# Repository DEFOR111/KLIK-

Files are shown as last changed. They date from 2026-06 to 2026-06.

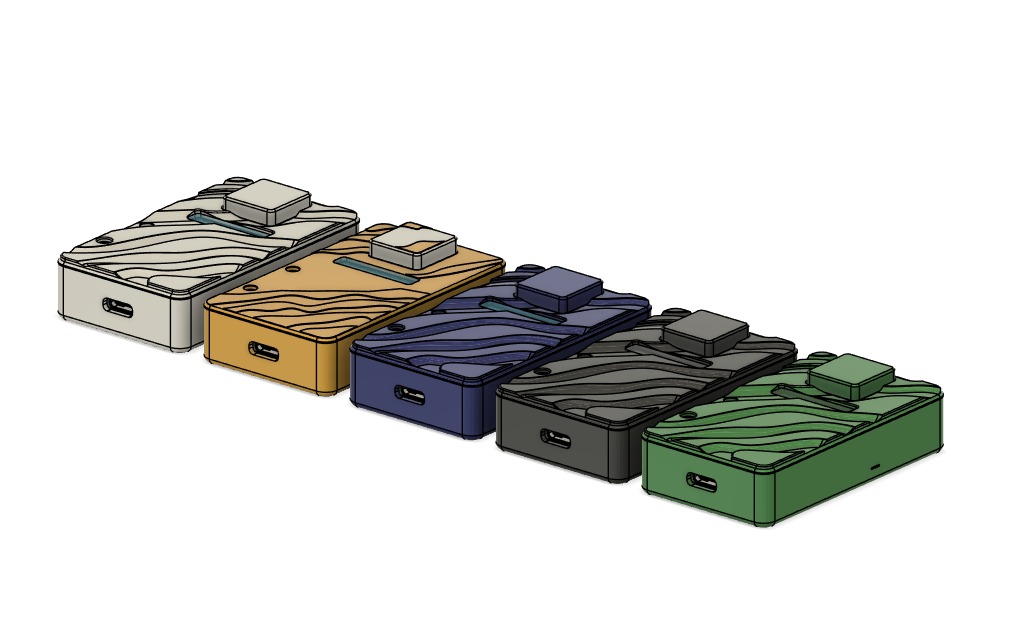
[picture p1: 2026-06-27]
Renders/5 KLIK side view.jpeg

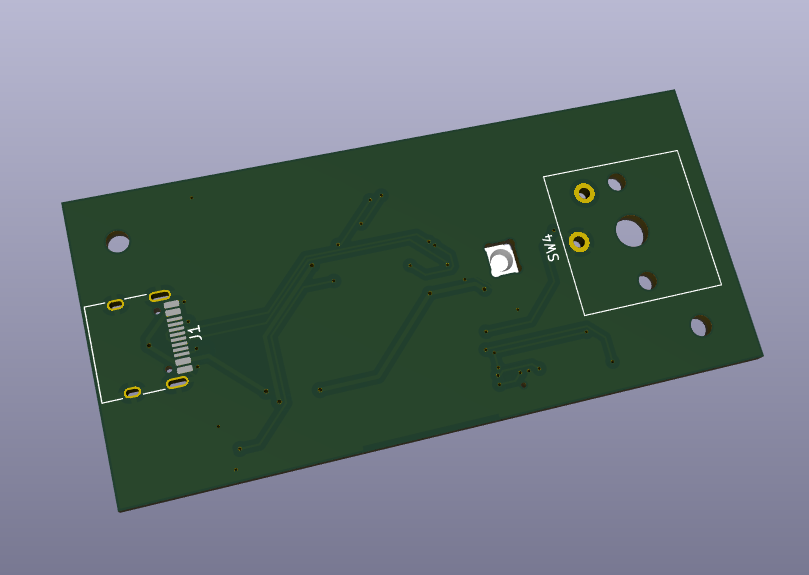
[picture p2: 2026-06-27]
Renders/Top PCB view.png

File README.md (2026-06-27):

# KLIK 
klik is small pocked size device for capturing the ideas or just notes with beatiful design and 5 colors 
WhatsApp Image 2026-06-02 at 11 36 02 AM
front view
WhatsApp Image 2026-06-02 at 11 36 16 AM
up view
WhatsApp Image 2026-06-02 at 11 38 32 AM
best view\
# What does it do? 
* 1. click : the device uses low profile switch which makes it compact and great at the same time
* 2. microphone : captures any idea you say cool thing
* 3. no screen i used screen in first version but its actully useless so now it workd with rgb which gives all feedback you need
* 4. vibration : it is virbrated and make using and cliking it really amazing
# the device parts 
* the device is not just a micphone you can always capture your ideas notions and any staff you want and customize it by easily removing the keycap and using any colour you want making it not only the capture device it is beatiluf custom second brain
* # bom
* you can buy whole parts just for +-90 dollars which makes building not that expensive check all components in BOM.csv
  # PCB
  Снимок экрана 2026-06-10 163932
Снимок экрана 2026-06-10 163853

# building 
to build this device you have to get all materials and then
1. solder full pcb
2. take bottom case screw the pcb place the vbiro motor
3.  then screw the battery holder
4.  after placing battery and all components screw the top case glue the rgb window smoke it with film
5.  put the keycap on switch
6.  turn it on and enjoy

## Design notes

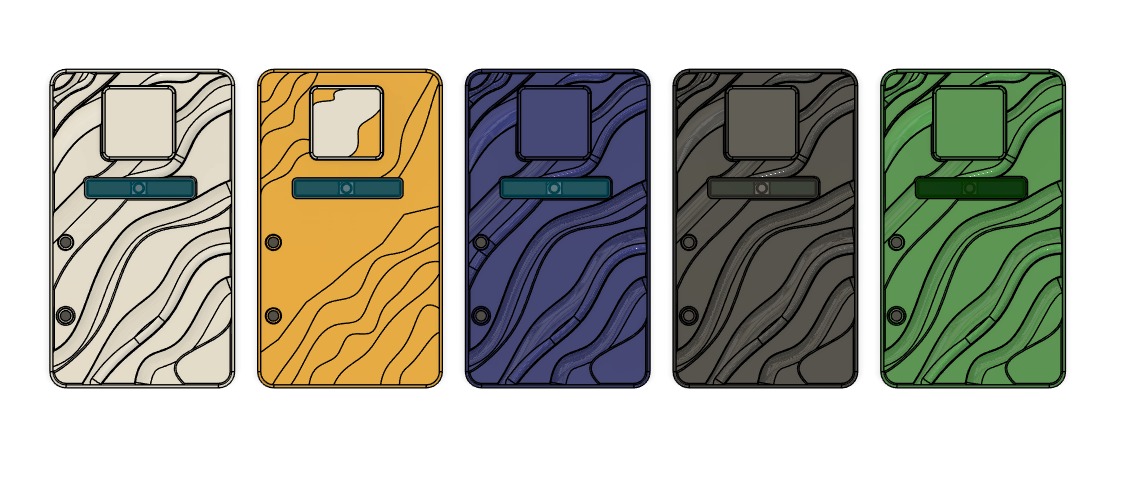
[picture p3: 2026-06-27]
Renders/5KLIK top view.jpeg

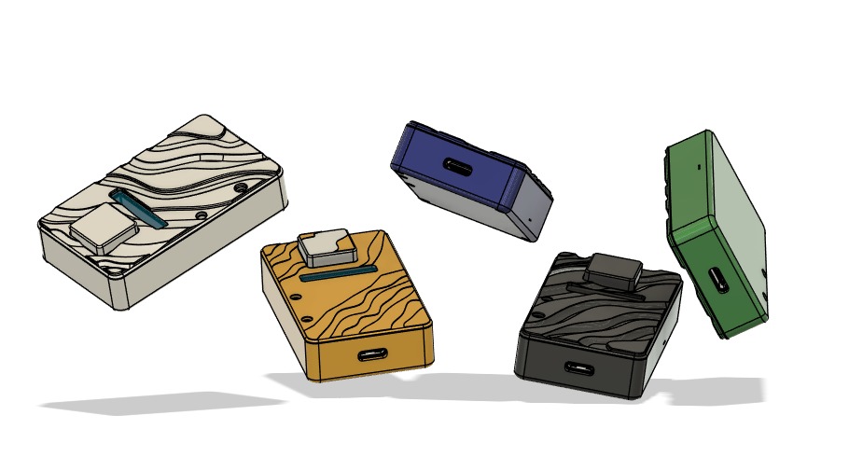
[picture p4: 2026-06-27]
Renders/flying 5 KLIk view.jpeg

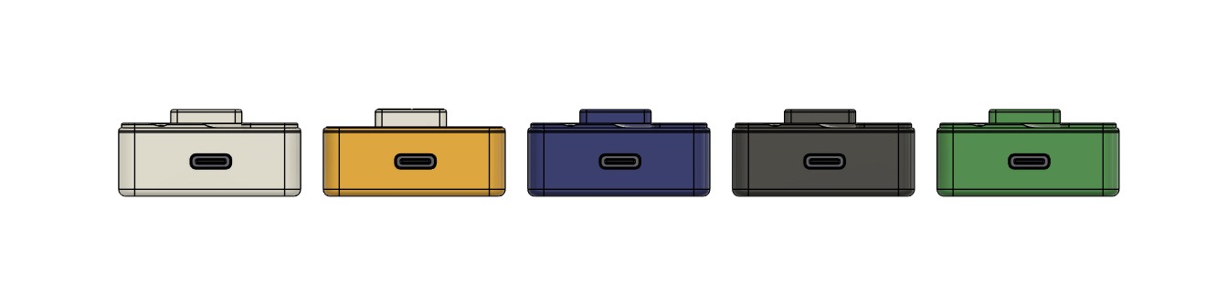
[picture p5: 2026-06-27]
Renders/5 KLIK front view.jpeg

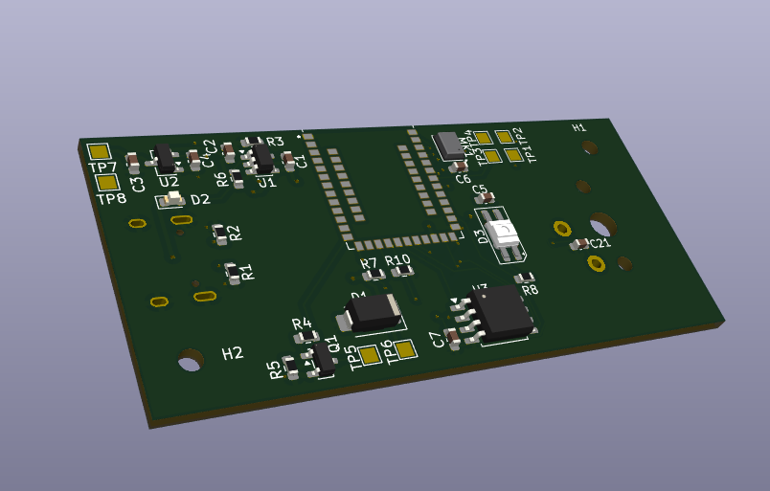
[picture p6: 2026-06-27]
Renders/Bottom PCB view.png

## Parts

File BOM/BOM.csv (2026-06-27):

SHEMATIC | NAME | PURPOSE | SOURSE | PRICE | LINK
R1,R2 | RESISTOR | PCB | ALIEXPRESS | $1.22 | https://aliexpress.ru/item/1005011982912733.html?sku_id=12000057190323324
R3 | RESISTOR | PCB | ALIEXPRESS | $1.22 | https://aliexpress.ru/item/1005011982912733.html?sku_id=12000057190323323
R4 | RESISTOR | PCB | ALIEXPRESS | $1.22 | https://aliexpress.ru/item/1005011982912733.html?sku_id=12000057190323307
R5 | RESISTOR | PCB | ALIEXPRESS | $1.22 | https://aliexpress.ru/item/1005011982912733.html?sku_id=12000057190323331
R6 | RESISTOR | PCB | ALIEXPRESS | $1.22 | https://aliexpress.ru/item/1005011982912733.html?sku_id=12000057190323295
R7,R8 | RESISTOR | PCB | ALIEXPRESS | $1.22 | https://aliexpress.ru/item/1005011982912733.html?sku_id=12000057190323355
C1,C2,C3,C4 | CAPCITOR | PCB | ALIEXPRESS | $1.5 | https://aliexpress.ru/item/1005009307420068.html?sku_id=12000048689741619
C5,C6,C7,C8 | CAPCITOR | PCB | ALIEXPRESS | $1.5 | https://aliexpress.ru/item/1005009307420068.html?sku_id=12000048689741619
J1 | USB_C | PCB | ALIEXPRESS | $1.39 | https://aliexpress.ru/item/1005007694777041.html?sku_id=12000041875830364
U1 | MCP73831 | PCB | ALIEXPRESS | $0.77 | https://aliexpress.ru/item/32800332566.html?sku_id=64192580147
U2 | XC6206P332MR | PCB | ALIEXPRESS | $1.07 | https://aliexpress.ru/item/32426685794.html?sku_id=56198345681
U3 | W25Q128JVSIQ | PCB | ALIEXPRESS | $1.08 | https://aliexpress.ru/item/1005007482599425.html?sku_id=12000040932519740
U4 | Holyiot 18010 Nordic NRF52840 | PCB | ALIEXPRESS | $7.51 | https://aliexpress.ru/item/32951888809.html?sku_id=66335833131
MK1 | ICS-43434 | PCB | ALIEXPRESS | $3.2 | https://aliexpress.ru/item/1005005656626703.html?sku_id=12000033910963847
Q1 | AO3400 | PCB | ALIEXPRESS | $1.63 | https://aliexpress.ru/item/1005010124516105.html?sku_id=12000051226992647
D1 | SMA SS14 | PCB | ALIEXPRESS | $1.42 | https://aliexpress.ru/item/1005012055431729.html?sku_id=12000057409264803
D2 | SK6812 MINI-E RGB | PCB | ALIEXPRESS | $3.5 | https://aliexpress.ru/item/1005003056797785.html?sku_id=12000023624298356
SW1 | Kailh Choc Low Profile Switch 1350 | PCB | ALIEXPRESS | $7.06 | https://aliexpress.ru/item/1005006217606250.html?sku_id=12000036325072485
NO | 0827 MOTOR | FOR VIBRATION FEEDBACK | ALIEXPRESS | $2.34 | https://aliexpress.ru/item/1005006234307356.html?sku_id=12000036399594976
NO | LIPO 250mAh BATTERY | POWER | ALIEXPRESS | $7.92 | https://aliexpress.ru/item/1005008702766764.html?sku_id=12000046312476228
NO | ACRYL SHEET 1MM | THE RGB WINDOW | ALIEXPRESS | $4.36 | https://aliexpress.ru/item/1005012007369276.html?sku_id=12000057277900079
NO | Gloss Transparent Light Black Smoke PVC Film Tint | THE RGB WINDOW COVER | ALIEXPRESS | $5.55 | https://aliexpress.ru/item/1005006752330496.html?sku_id=12000038188853118
NO | 3D Printer Filament PETG 1.75mm 1kg/2.2lbs | CASE PRINTING | ALIEXPRESS | $19.87 | https://aliexpress.ru/item/2042369676.html?sku_id=12000015581361162
NO | INSERTS M1.4 | FOR SCREWS | ALIEXPRESS | $1.1 | https://aliexpress.ru/item/1005006273163364.html?sku_id=12000036559261036
NO | SCREWS M1.4 | TO HOLD EVETHING TOGETHER | ALIEXPRESS | $1.03 | https://aliexpress.ru/item/1005007870922575.html?sku_id=12000042628835105
TOTAL PRICE | taxes and delivery | $91.26

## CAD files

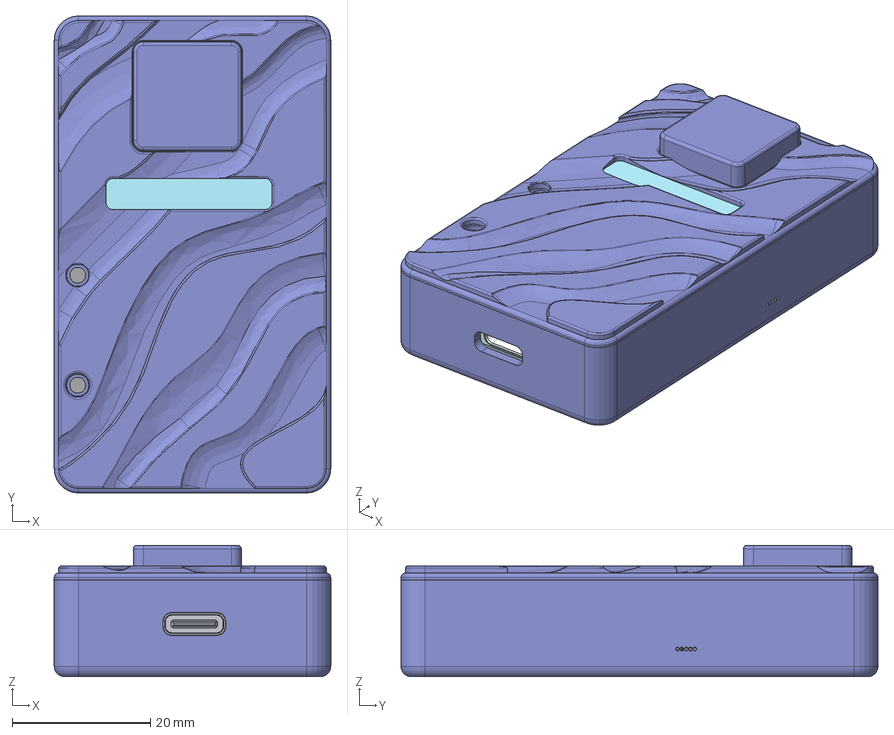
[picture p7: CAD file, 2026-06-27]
Cad/KLIK full CAD.step
40.0 x 69.0 x 19.0 mm

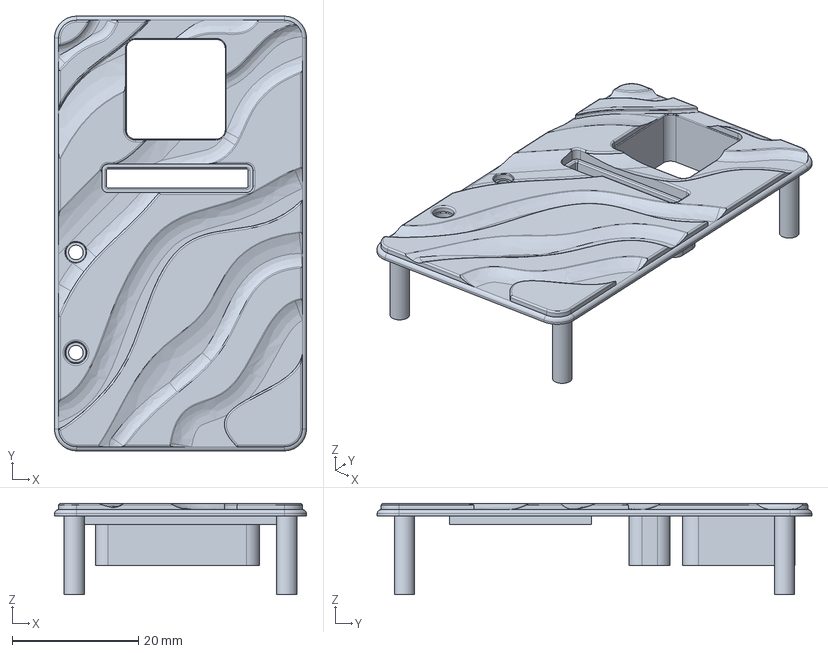
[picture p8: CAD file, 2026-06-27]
Cad/top case.step
40.0 x 69.0 x 14.5 mm

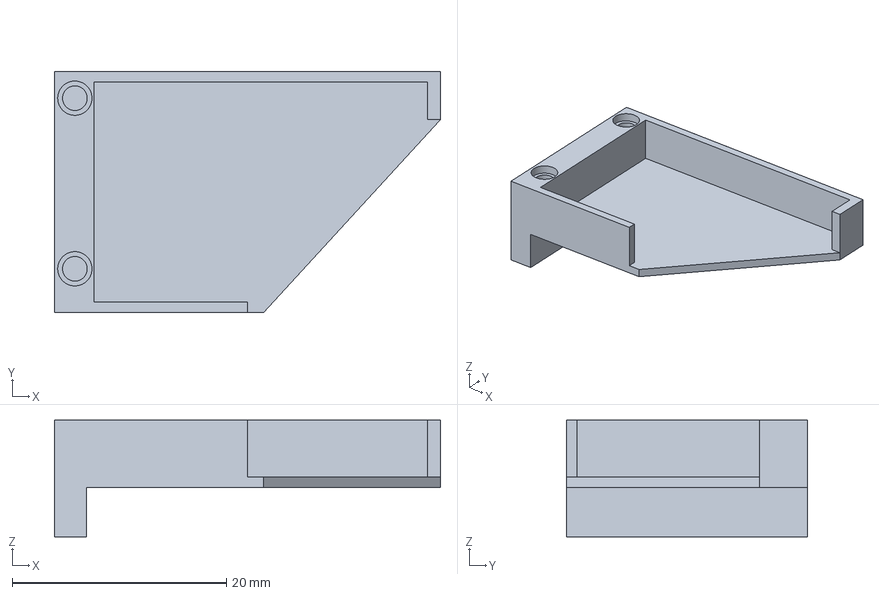
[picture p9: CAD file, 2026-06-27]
Cad/battery hold.step
36.0 x 22.5 x 10.9 mm

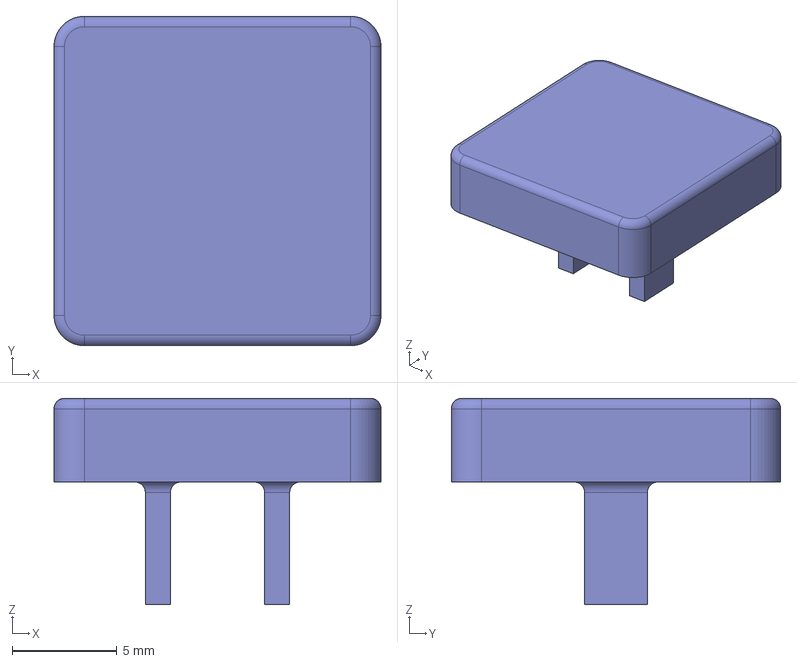
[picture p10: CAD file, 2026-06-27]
Cad/keycap.step
15.6 x 15.7 x 9.86 mm

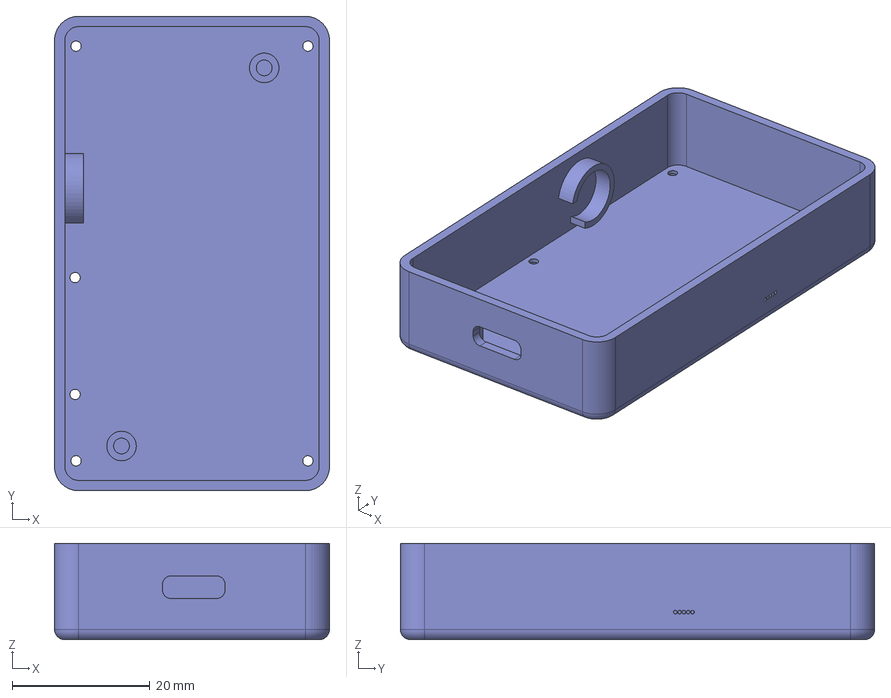
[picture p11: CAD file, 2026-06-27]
Cad/Bottom case.step
40.0 x 69.0 x 14.0 mm

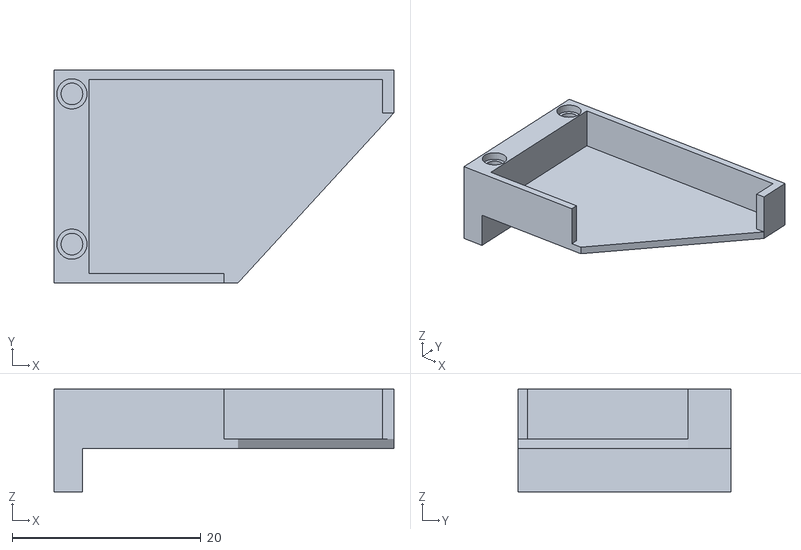
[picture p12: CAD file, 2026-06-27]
Cad/battery+holder.stl
36.0 x 22.5 x 10.9

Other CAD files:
Cad/KEYCAP.stl
Cad/battery hold.f3d
Cad/bottom case.f3d
Cad/bottom+case.stl
Cad/keycap.f3d
Cad/top case.f3d
Cad/top+case.stl

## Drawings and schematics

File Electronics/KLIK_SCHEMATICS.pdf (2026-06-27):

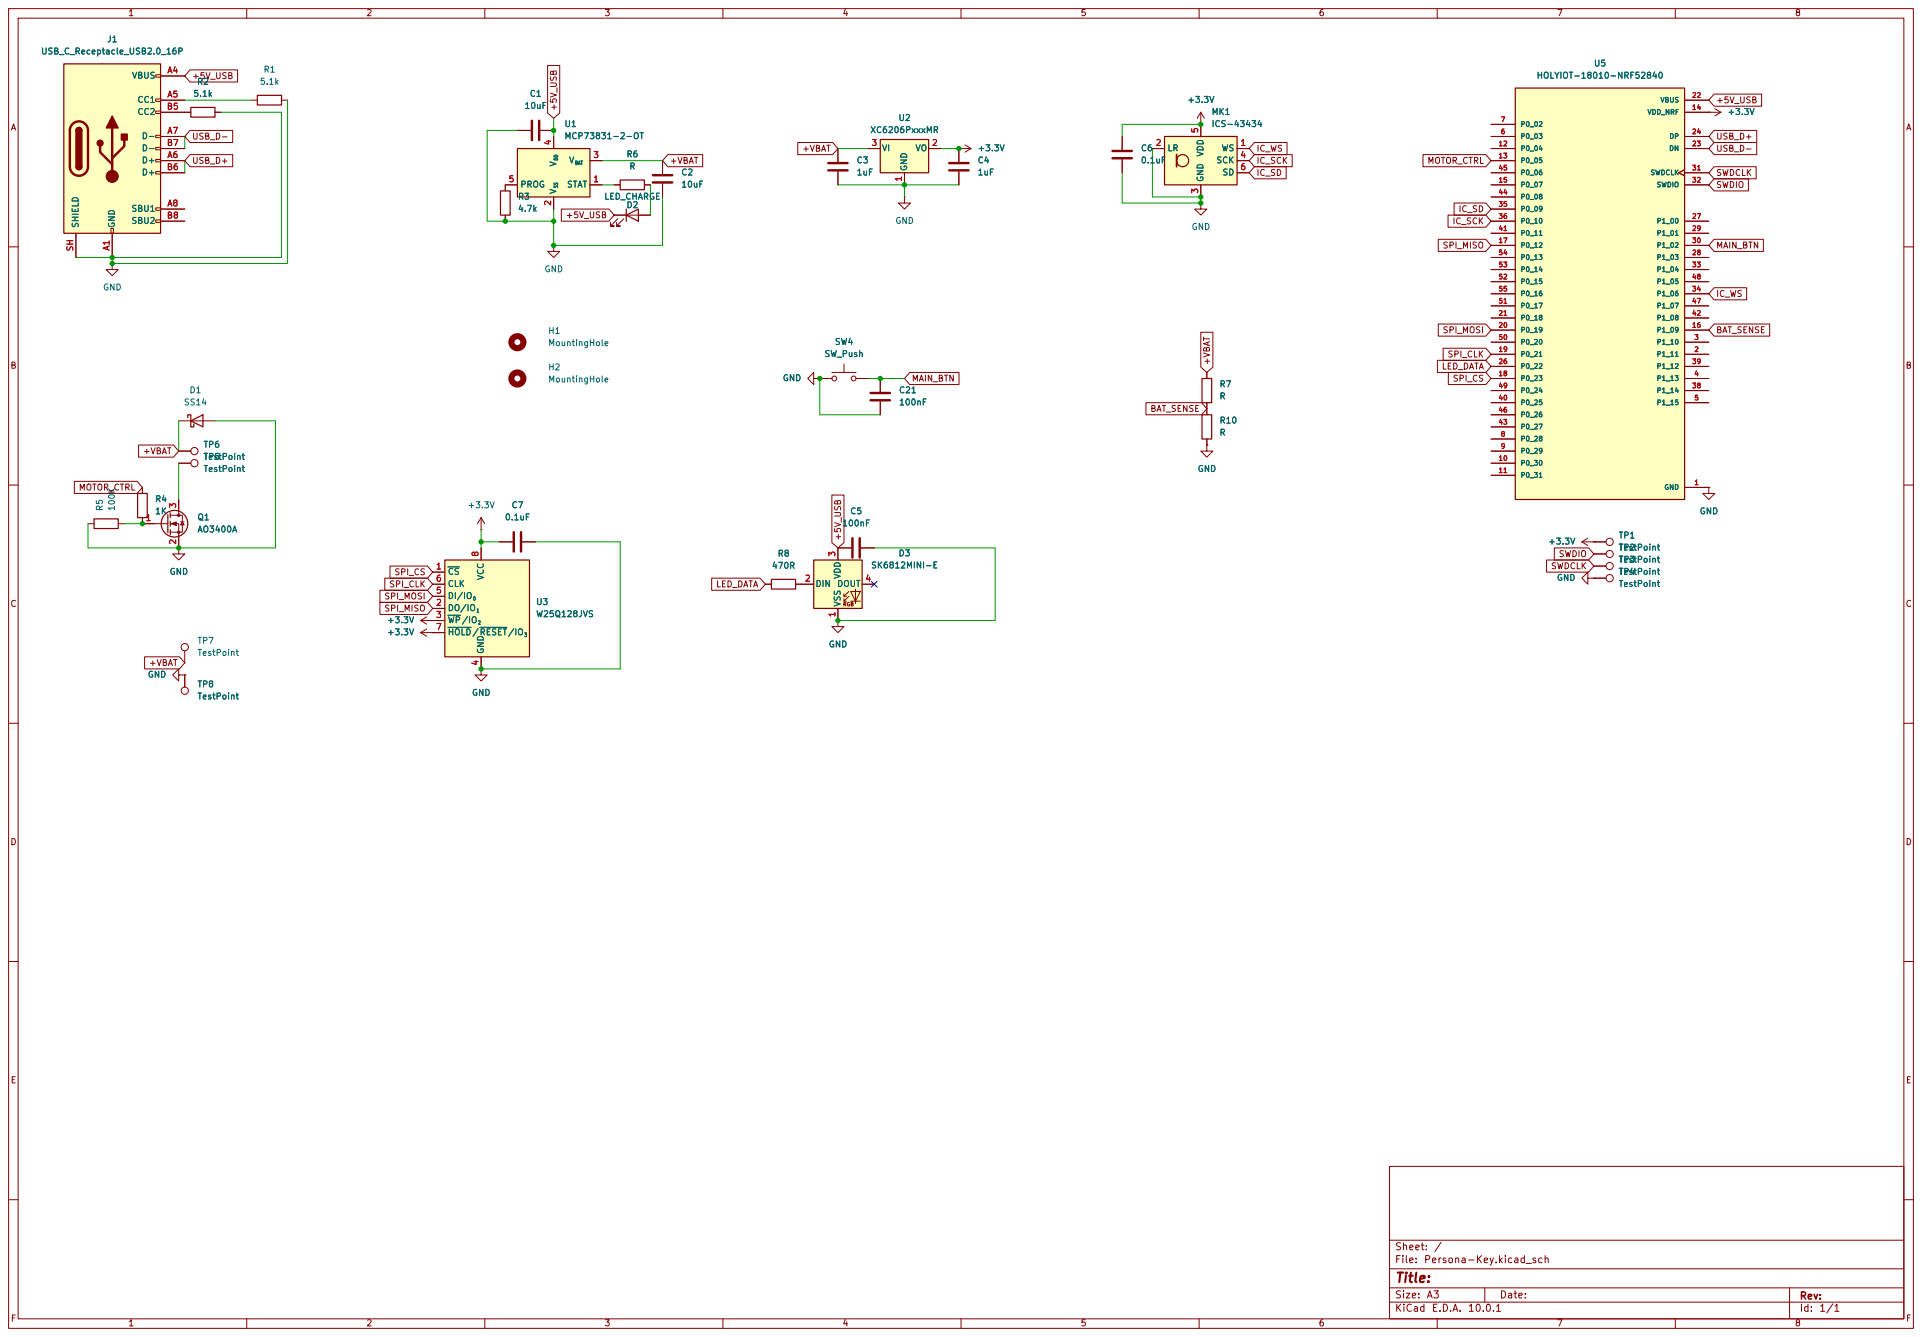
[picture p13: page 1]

4 DI/IO0 5 CLK 6 HOLD/RESET/IO3 7 VCC

Size: A3 | Rev: | F Date:
KiCad E.D.A. 10.0.1 | Id: 1/1

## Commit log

2026-06-27 READMe added
    Updated README to provide detailed information about the KLIK device, including its features, parts, and building instructions.
2026-06-27 Rename Снимок экрана 2026-06-27 161025.png to Ali cart photo
2026-06-27 Rename Снимок экрана 2026-06-27 161032.png to Ali cart photo2
2026-06-27 Rename Снимок экрана 2026-06-27 161038.png to Ali cart photo3
2026-06-27 Rename Снимок экрана 2026-06-27 161046.png to Ali cart photo4
2026-06-27 Rename Снимок экрана 2026-06-27 161052.png to Ali cart photo5
